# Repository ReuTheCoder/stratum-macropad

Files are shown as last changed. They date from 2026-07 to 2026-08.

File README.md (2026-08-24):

# Stratum 
Stratum is a 9-key personal macropad creation with a rotary encoder, an OLED display and RGB backlighting under each key that uses QMK firmware. It supports five independent layers, allowing each key to perform a unique function depending on the active layer. Stratum was made as a submission for [Hackpad v5](https://hackpad.hackclub.com/) through HackClub's Stardance Challenge.

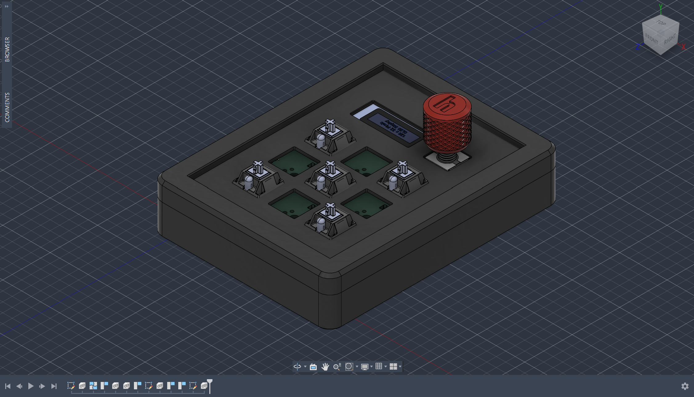
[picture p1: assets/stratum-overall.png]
Screenshot of overall macropad

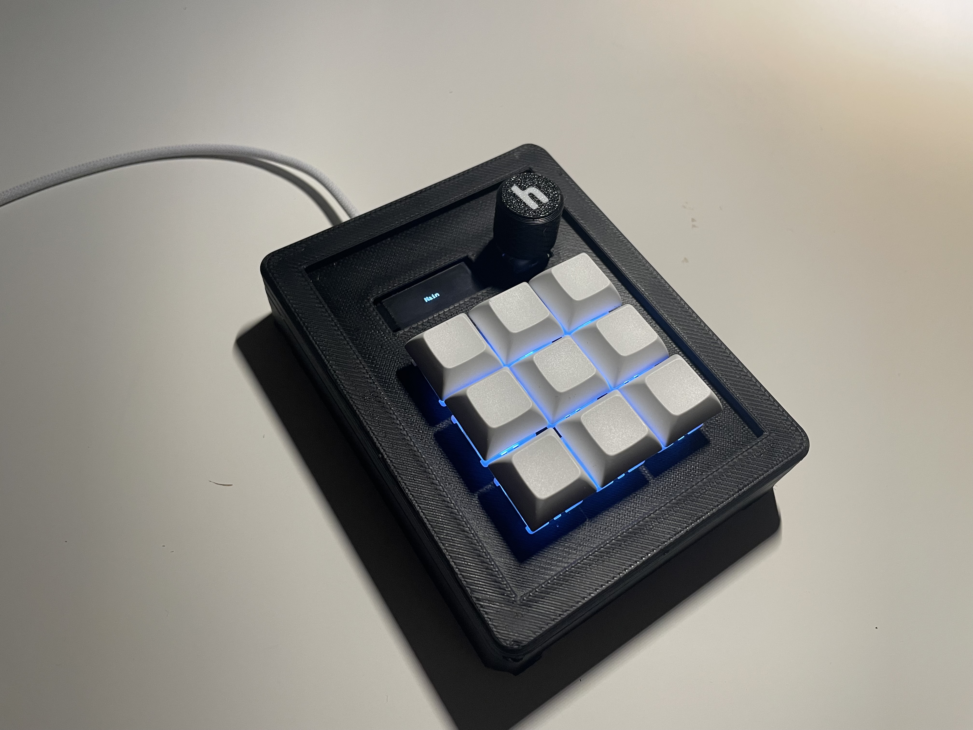
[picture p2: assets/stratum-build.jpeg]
Screenshot of final macropad build


## Features:
- 0.91 inch OLED display
- A EC11 Rotary encoder (push button diabled)
- 9 MX-Style switches with DSA keycaps
- 9 accompanying SK6812 MINI-E LEDs for backlighting

## PCB
This is the PCB I made for Stratum; made in KiCad 10.0. Most of the footprints were provided by HackClub. Anything else was from KICad's default libraries or was sourced through peers on the HackClub Slack. The silkscreen uses HackClub's logo and a character from the Stardance Challenge.

**Schematic:**

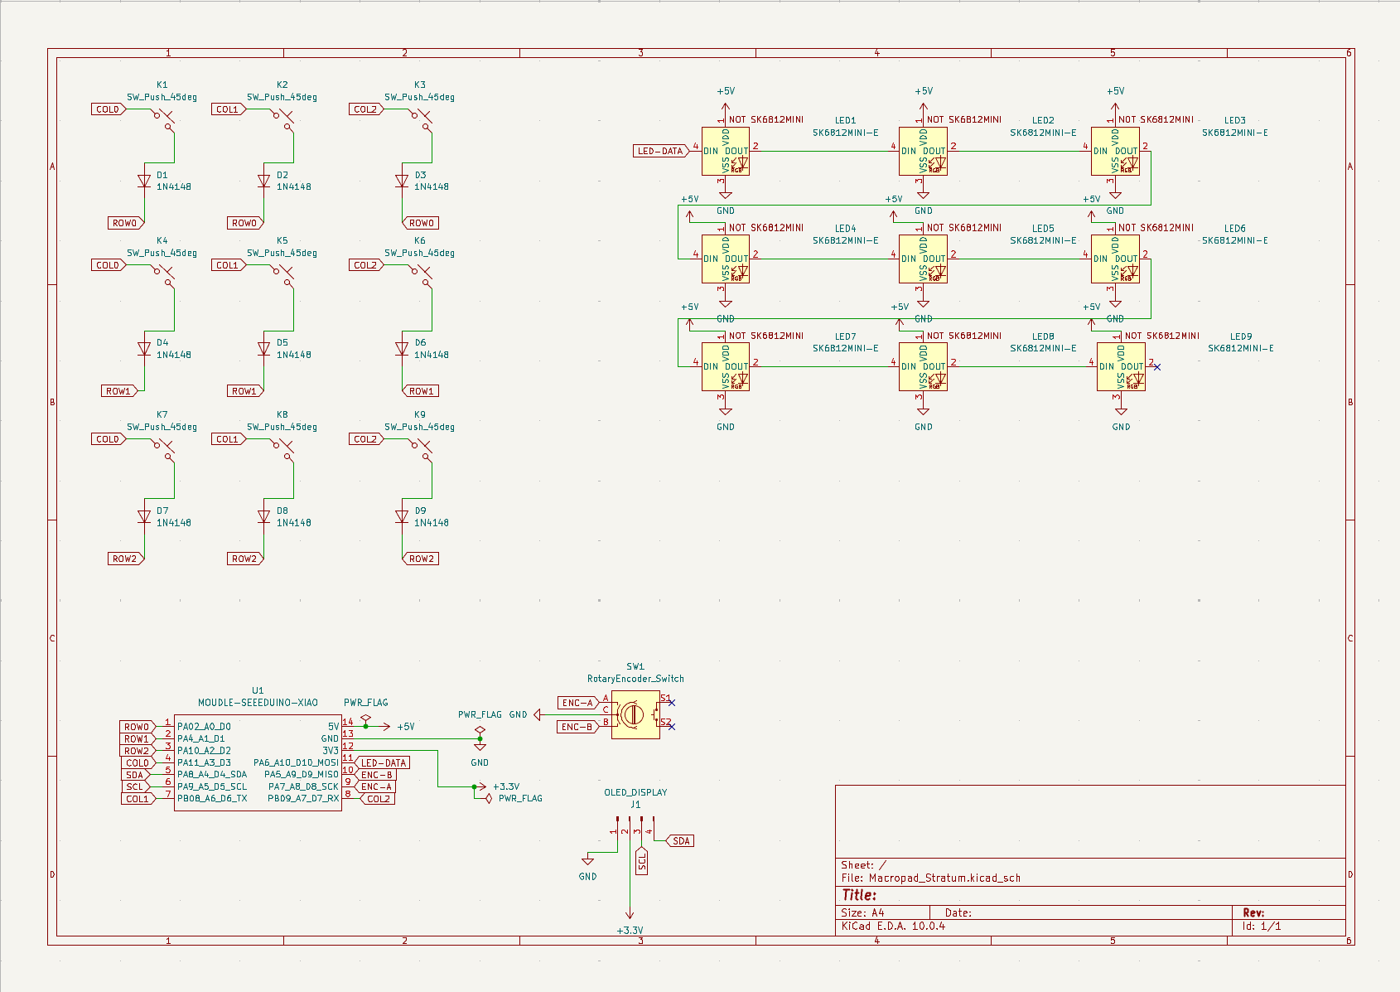
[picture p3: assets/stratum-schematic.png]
Screenshot of schematic


**PCB:**

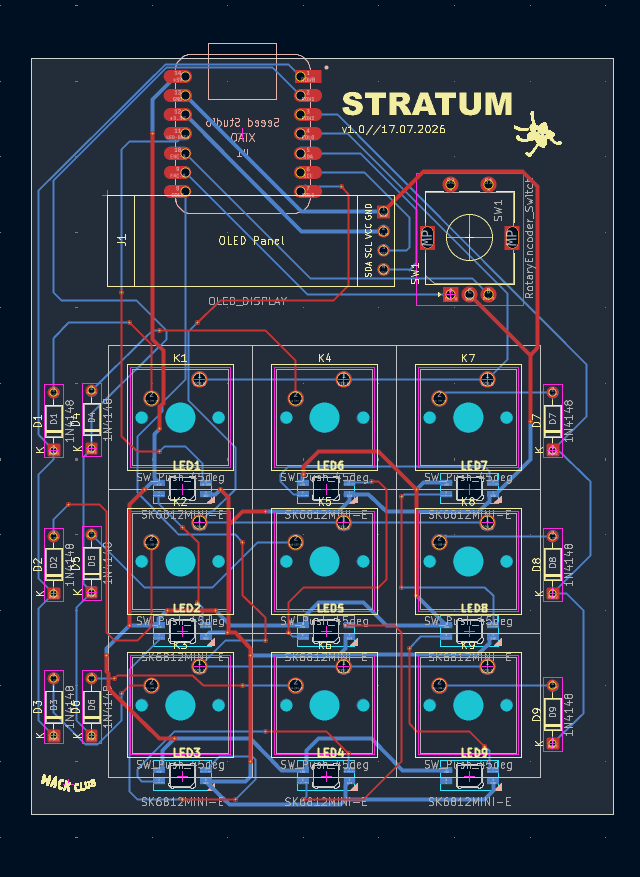
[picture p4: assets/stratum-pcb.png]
Screenshot of PCB in KiCAd's footprint editor


## CAD Model
This CAD model, designed in Fusion 360, utilizes an integrated plate keyboard mount style - so it only has a top and bottom piece that are connected together with four 16mm M3 bolts that are screwed in from the bottom of the case. Right now, the case relies on self-threading since I don't anticipate needing to unscrew the macropad often after assembly. Realistically, I have noted I will need to add heat-set inserts in a future version to ensure its long-term survival. The rotary encoder cap was provided by HackClub. 

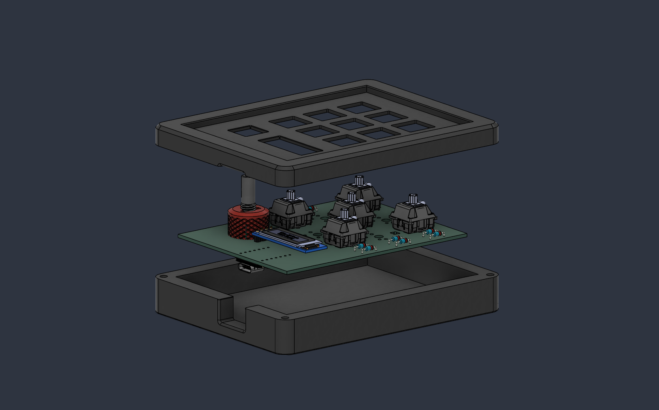
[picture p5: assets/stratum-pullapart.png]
Screenshot of CAD Model


## Firmware Overview
The name Stratum reflects this macropad's ability to swap between 5 distinct layers through QMK firmware. This is done through a Settings mode in which you must hold down three center keys until the OLED displays a selection menu where you can use the rotary encoder to scroll through the 5 different layers. You select with the lower-right key. An overview of notable firmware features are:

- 5 Different Layers: Main, Productivity, Design, Scientific and Media. The keys and rotary encoder change functions on each mode
- The OLED that displays current layer, settings menu and a transition animation
- RGB Backlights change color on each layer
- A sleep and brightness control in settings
- Rotary encoder volume control

The 5 layers will likely be updated as I use the macropad and see what does and does not work. A future idea I have in mind is adding VIA support for quick macro functionality edits.

## Bill of Materials [BOM]:
All the components needed for this macropad design:
- 9x Cherry MX Switches
- 9x DSA Keycaps
- 4x M3x16mm screws
- 9x through-hole 1N4148 Diodes
- 9x SK6812 MINI-E LEDs (reverse mount)
- 1x 0.91 inch OLED display (128x32)
- 1x EC11 Rotary encoder
- 1x XIAO RP2040
- 1x Case (2 printed parts + optional Rotary Encoder Cap)
  
## Additional Notes
This was my first time completely designing a piece of hardware from scratch. I used this project as an opportunity to learn PCB design through KiCad (both things I have never done before) and become accustomed to a new CAD program (before this, I had only used Tinkercad for 3D printing). This project also served as an introduction to QMK firmware. Although this project greatly increased my understanding of it (as I already had some experience coding arduino in C++), I still need more time writing QMK firmware to become comfortably familiar with it (I had a lot of external help when writing my firmware). Although it seemed to compile correctly, I have no idea if it will work as expected once I flash it to the RP2040. 

### Firmware Layer-Specific Functions
Layer 0 - Main <br>
&emsp;       K1 Save | K2  (close/escape) | K3 Refresh <br>
&emsp;       K4 File Explorer | K5 Settings | K6 Task Manager <br>
&emsp;       K7 Emoji Panel | K8 Screenshot | K9 Calculator <br>

Layer 1 - Productivity (Docs) <br>
&emsp;    K1 Citations | K2  Spell Check| K3 Clear Formatting <br>
&emsp;     K4 Align Left| K5 Center | K6 Align Right <br>
&emsp;     K7 Find | K8 Insert Link| K9 Print <br>

Layer 2 -  Design <br>
&emsp;     K1 Undo | K2 Redo | K3 Duplicate <br>
&emsp;     K4 Group | K5 Ungroup | K6 Bring Forward <br>
&emsp;     K7 Zoom In | K8 Zoom Out  | K9 Fit Screen <br>

Layer 3 -  Scientific (Docs) <br>
&emsp;     K1 ° | K2 ±  | K3 × <br>
&emsp;     K4 √  |  K5 π  | K6 Σ <br>
&emsp;     K7 Superscript | K8 Subscript  | K9 Open Latex Editor <br>

Layer 4 -  Media <br>
&emsp;     K1 Play  | K2 Pause  | K3 Stop <br>
&emsp;     K4 Previous  |  K5 Next  | K6 Mute <br>
&emsp;     K7 Spotify | K8 Youtube | K9 Libby (Audiobook App) <br>

Thank you so much to @qcoral and the rest of the organizers of [Stardance](https://stardance.hackclub.com/missions/hackpad) and HackClub for this wonderful hardware exploration opportunity!

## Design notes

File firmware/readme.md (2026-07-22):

# stratum

stratum

*A short description of the keyboard/project*

* Keyboard Maintainer: [Reuben O](https://github.com/ReuTheCoder)
* Hardware Supported: *The PCBs, controllers supported*
* Hardware Availability: *Links to where you can find this hardware*

Make example for this keyboard (after setting up your build environment):

    make stratum:default

Flashing example for this keyboard:

    make stratum:default:flash

See the [build environment setup](https://docs.qmk.fm/#/getting_started_build_tools) and the [make instructions](https://docs.qmk.fm/#/getting_started_make_guide) for more information. Brand new to QMK? Start with our [Complete Newbs Guide](https://docs.qmk.fm/#/newbs).

## Bootloader

Enter the bootloader in 3 ways:

* **Bootmagic reset**: Hold down the key at (0,0) in the matrix (usually the top left key or Escape) and plug in the keyboard
* **Physical reset button**: Briefly press the button on the back of the PCB - some may have pads you must short instead
* **Keycode in layout**: Press the key mapped to `QK_BOOT` if it is available

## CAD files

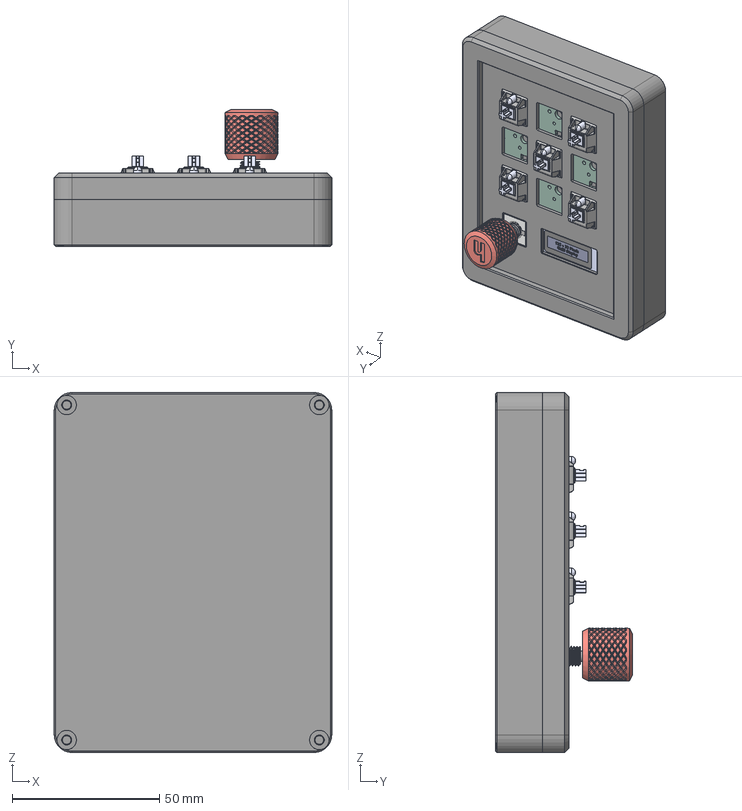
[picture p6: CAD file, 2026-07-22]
cad/macropad-stratum-assembly_v1.step
94.4 x 46.6 x 122.4 mm

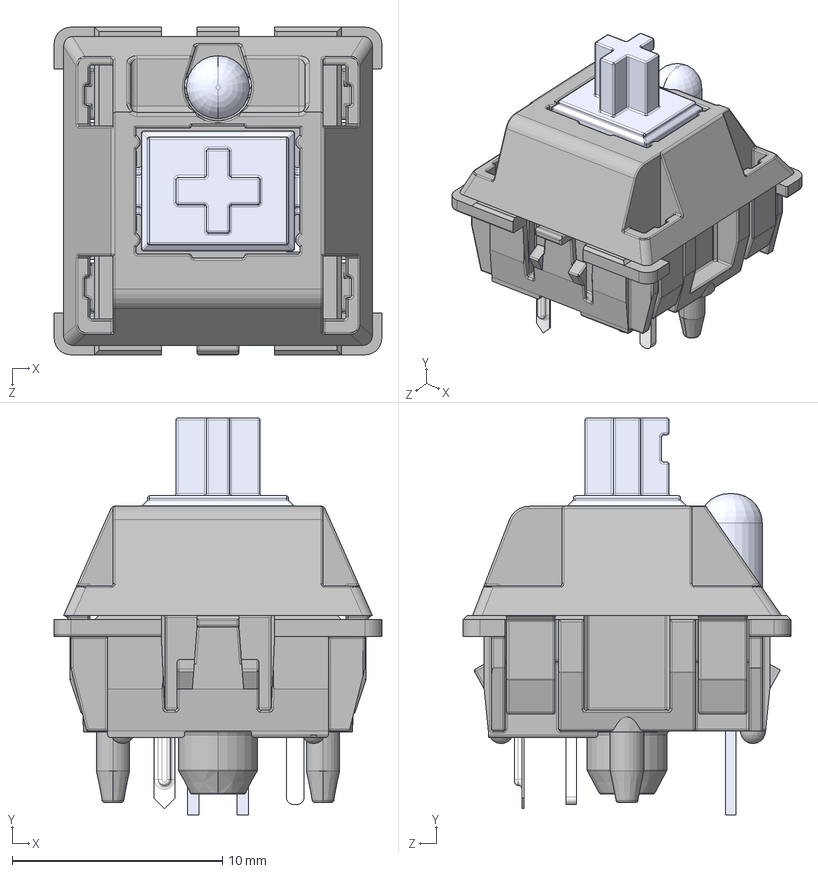
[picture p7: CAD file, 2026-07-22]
pcb/assets/MX .STEP
15.6 x 18.9 x 15.6 mm
MX 轴 按键′_ü___¨1
MX 轴 轴体áì_¨￠¨__
MX粣 拸簽LEDLEDLED
MX轴 轴体 底部 μ×2__默认_á2____è_
针脚___默认__è_

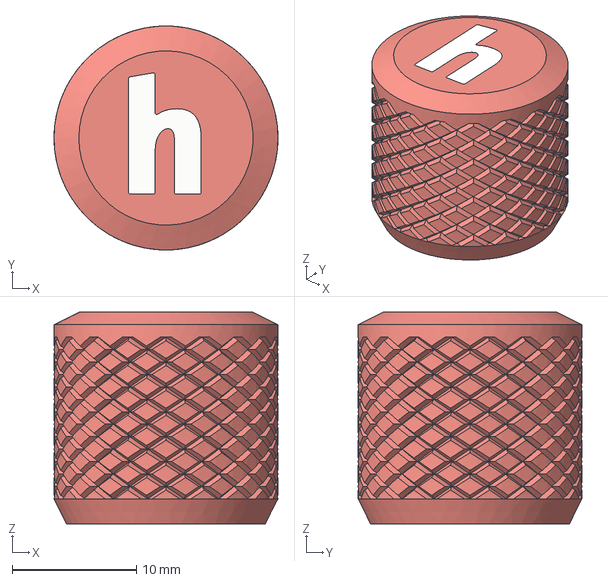
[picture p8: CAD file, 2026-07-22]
production/Hack Club Knurled Knob.step
18.0 x 18.0 x 17.0 mm
Base
H

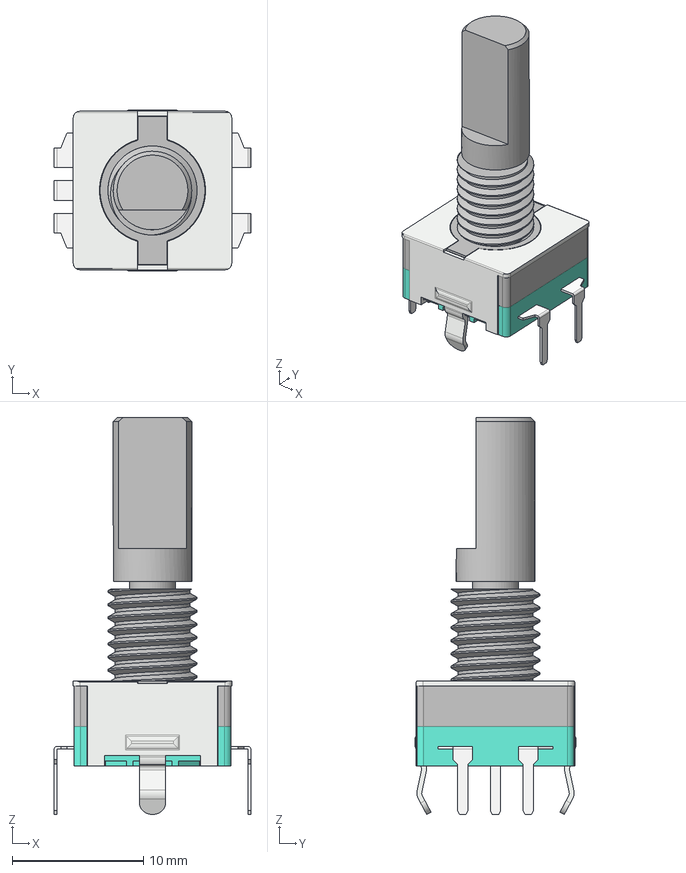
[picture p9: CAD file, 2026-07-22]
pcb/assets/EC11E_Switch_20mm.step
15.0 x 12.3 x 30.3 mm

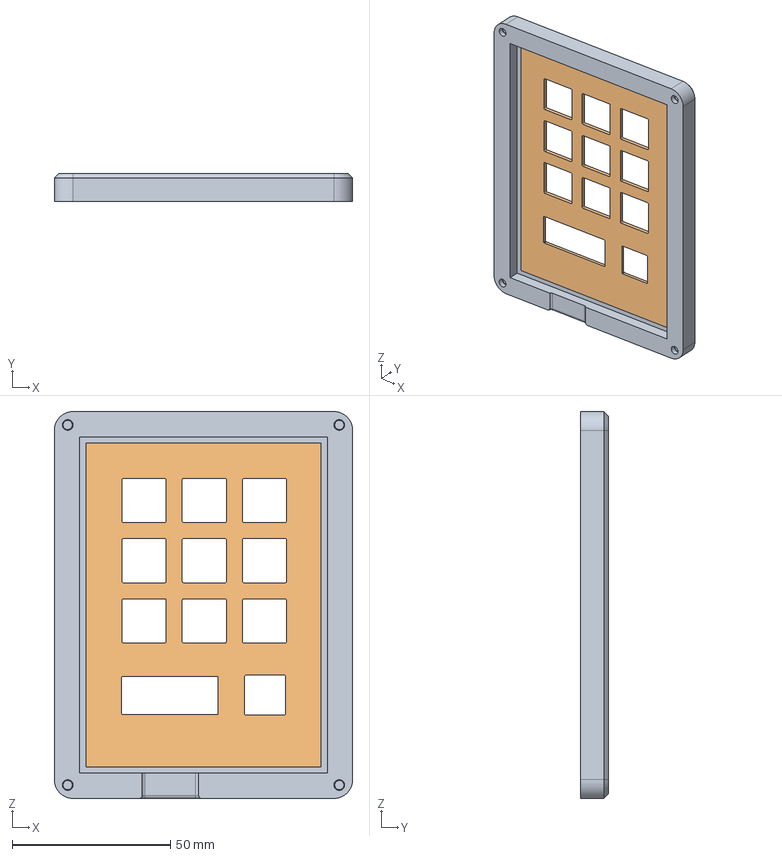
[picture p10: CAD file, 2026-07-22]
production/macropad-stratum-top.step
94.4 x 9.00 x 122.4 mm

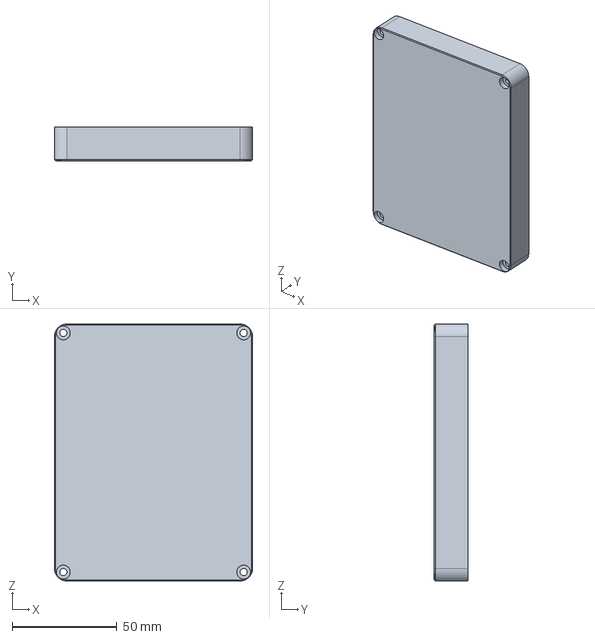
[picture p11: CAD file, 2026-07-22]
production/macropad-stratum-bottom.step
94.4 x 16.0 x 122.4 mm

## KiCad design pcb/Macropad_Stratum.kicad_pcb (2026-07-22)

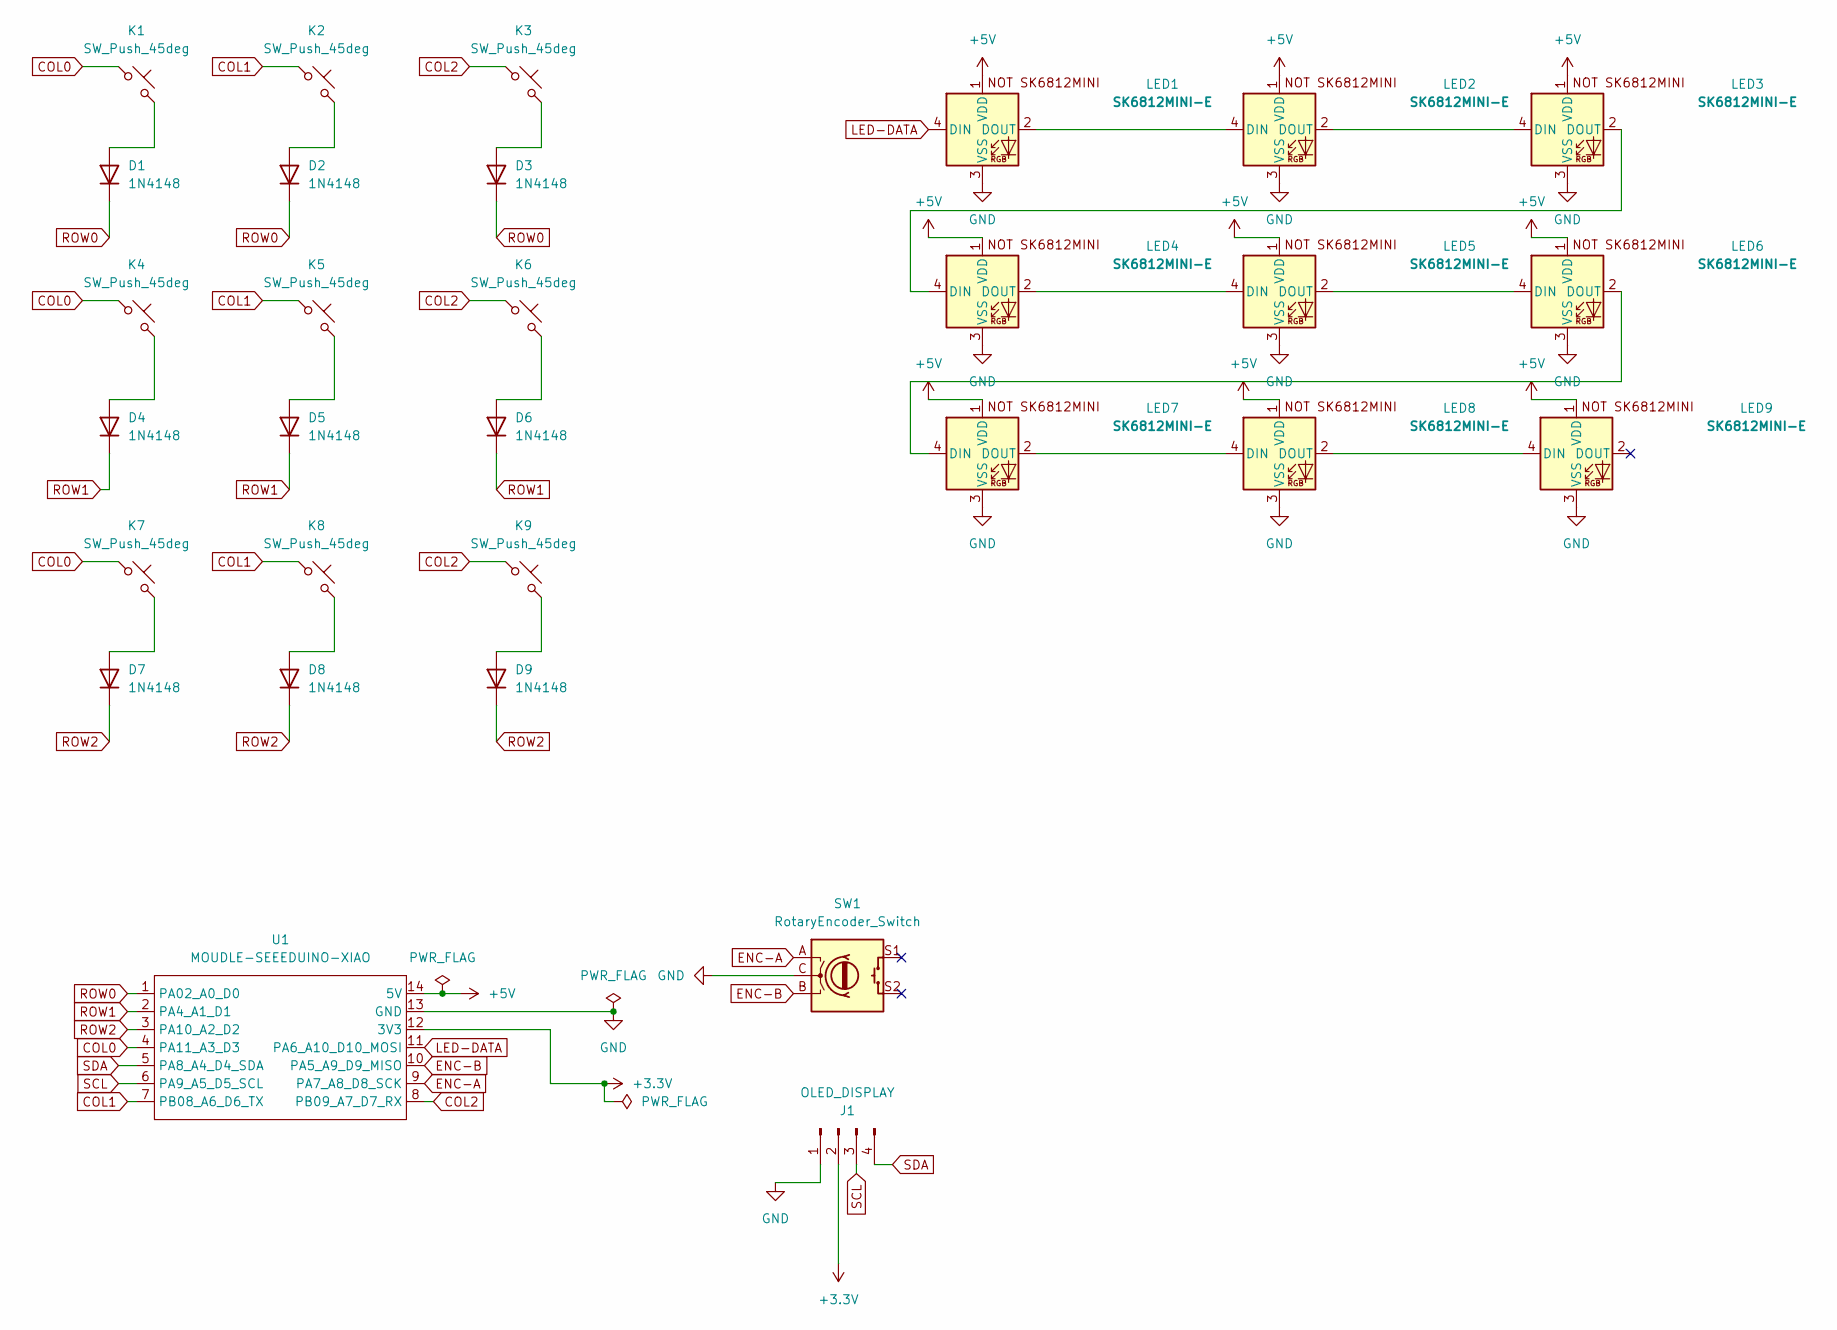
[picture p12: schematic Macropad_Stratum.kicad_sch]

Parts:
D1, D2, D3, D4, D5, D6, D7, D8, D9: 1N4148; D_DO-35_SOD27_P7.62mm_Horizontal
J1: OLED_DISPLAY; SSD1306-0.91-OLED-4pin-128x32
K1, K2, K3, K4, K5, K6, K7, K8, K9: SW_Push_45deg; SW_Cherry_MX_1.00u_PCB
LED1, LED2, LED3, LED4, LED5, LED6, LED7, LED8, LED9: SK6812MINI-E; SK6812MINI-E_fixed
SW1: RotaryEncoder_Switch; RotaryEncoder_Alps_EC11E-Switch_Vertical_H20mm
U1: MOUDLE-SEEEDUINO-XIAO; XIAO-Generic-Hybrid-14P-2.54-21X17.8MM

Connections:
+3.3V: J1.2, U1.12 (3V3)
+5V: LED1.1 (VDD), LED2.1 (VDD), LED3.1 (VDD), LED4.1 (VDD), LED5.1 (VDD), LED6.1 (VDD), LED7.1 (VDD), LED8.1 (VDD), LED9.1 (VDD), U1.14 (5V)
COL0: K1.1, K4.1, K7.1, U1.4 (PA11_A3_D3)
COL1: K2.1, K5.1, K8.1, U1.7 (PB08_A6_D6_TX)
COL2: K3.1, K6.1, K9.1, U1.8 (PB09_A7_D7_RX)
ENC-A: SW1.A, U1.9 (PA7_A8_D8_SCK)
ENC-B: SW1.B, U1.10 (PA5_A9_D9_MISO)
GND: J1.1, LED1.3 (VSS), LED2.3 (VSS), LED3.3 (VSS), LED4.3 (VSS), LED5.3 (VSS), LED6.3 (VSS), LED7.3 (VSS), LED8.3 (VSS), LED9.3 (VSS), SW1.C, U1.13 (GND)
LED-DATA: LED1.4 (DIN), U1.11 (PA6_A10_D10_MOSI)
unnamed: D1.2 (A), K1.2
unnamed: D2.2 (A), K2.2
unnamed: D3.2 (A), K3.2
unnamed: D4.2 (A), K4.2
unnamed: D5.2 (A), K5.2
unnamed: D6.2 (A), K6.2
unnamed: D7.2 (A), K7.2
unnamed: D8.2 (A), K8.2
unnamed: D9.2 (A), K9.2
unnamed: LED1.2 (DOUT), LED2.4 (DIN)
unnamed: LED2.2 (DOUT), LED3.4 (DIN)
unnamed: LED3.2 (DOUT), LED4.4 (DIN)
unnamed: LED4.2 (DOUT), LED5.4 (DIN)
unnamed: LED5.2 (DOUT), LED6.4 (DIN)
unnamed: LED6.2 (DOUT), LED7.4 (DIN)
unnamed: LED7.2 (DOUT), LED8.4 (DIN)
unnamed: LED8.2 (DOUT), LED9.4 (DIN)
ROW0: D1.1 (K), D2.1 (K), D3.1 (K), U1.1 (PA02_A0_D0)
ROW1: D4.1 (K), D5.1 (K), D6.1 (K), U1.2 (PA4_A1_D1)
ROW2: D7.1 (K), D8.1 (K), D9.1 (K), U1.3 (PA10_A2_D2)
SCL: J1.3, U1.6 (PA9_A5_D5_SCL)
SDA: J1.4, U1.5 (PA8_A4_D4_SDA)

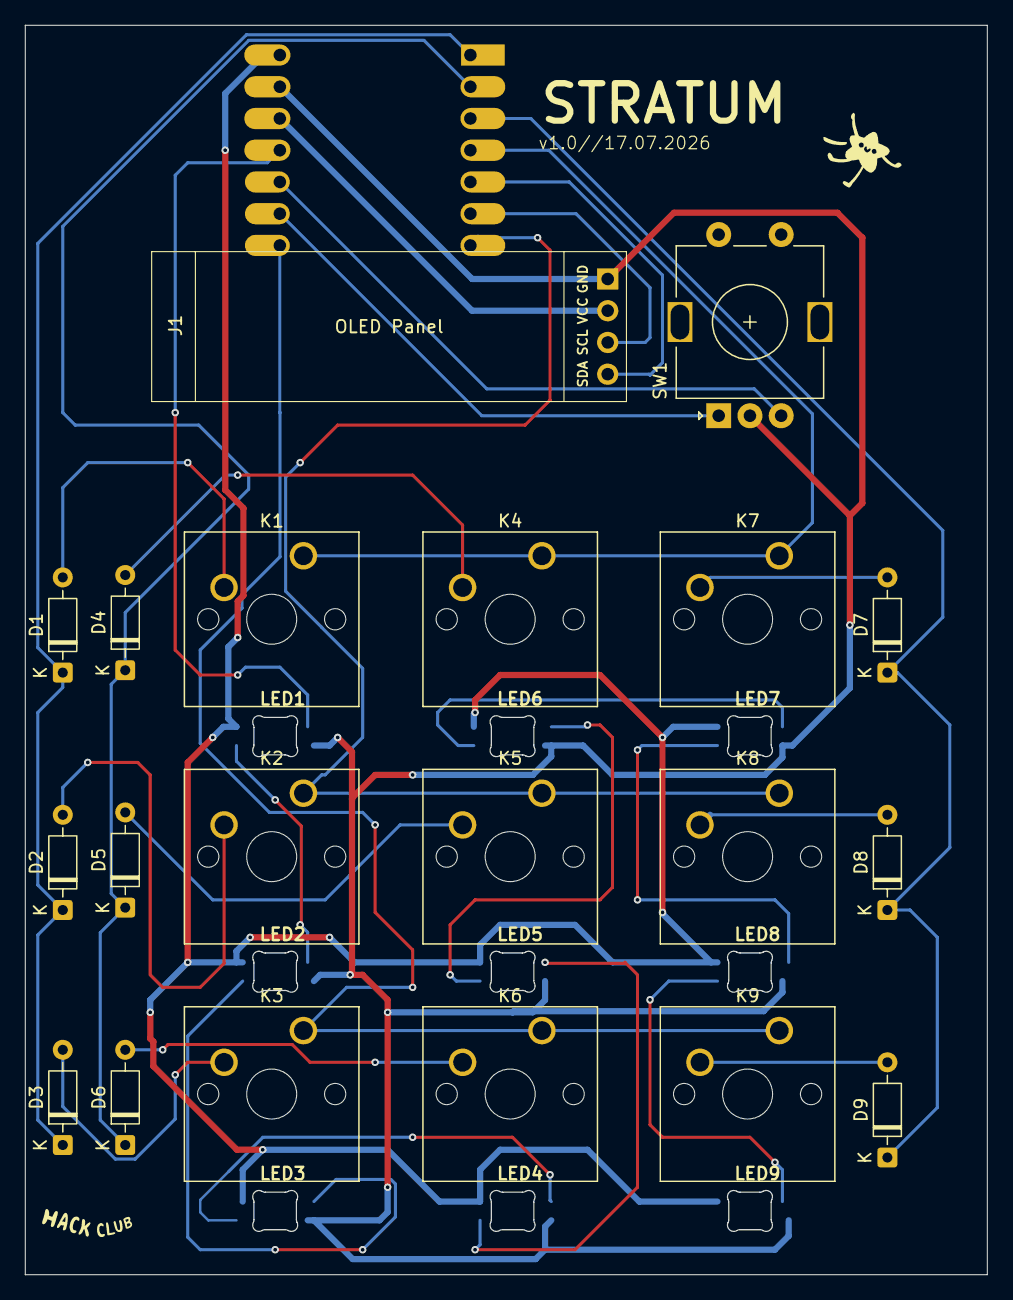
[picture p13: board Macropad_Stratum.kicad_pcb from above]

Board: 2 copper layers, 77.0 x 100.0 mm, 30 parts (1 on the bottom side), 31 nets.

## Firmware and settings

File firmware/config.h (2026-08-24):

#pragma once

/* Encoder resolution - one detent per step is common */
#define ENCODER_RESOLUTION 4

/* RGB brightness cap - safety headroom */
#define RGBLIGHT_LIMIT_VAL 200

/* OLED - SSD1306, 0.91" is typically 128x32 */
#define OLED_DISPLAY_128X32

/* I2C - override broken promicro_rp2040 board defaults with real pins */
#define I2C1_SDA_PIN GP6
#define I2C1_SCL_PIN GP7

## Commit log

2026-08-24 Resubmit corrected firmware files
    [config.h]
2026-08-24 Add corrected and functional firmware files
    [config.h]
